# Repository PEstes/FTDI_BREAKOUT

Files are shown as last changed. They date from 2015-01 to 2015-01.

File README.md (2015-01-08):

# FTDI_BREAKOUT

A full featured FTDI FT232R breakout board which features almost all UART pins(RX,TX,DTR,RTS,CTS) broken out and also IO voltage selection feature
to either 3.3v or 5v IO.

<br /><span xmlns:dct="http://purl.org/dc/terms/" property="dct:title">FTDI BREAKOUT</span> by <span xmlns:cc="http://creativecommons.org/ns#" property="cc:attributionName">NeutroN StrikeR</span> is licensed under a <a rel="license" href="http://creativecommons.org/licenses/by-sa/4.0/">Creative Commons Attribution-ShareAlike 4.0 International License</a>.

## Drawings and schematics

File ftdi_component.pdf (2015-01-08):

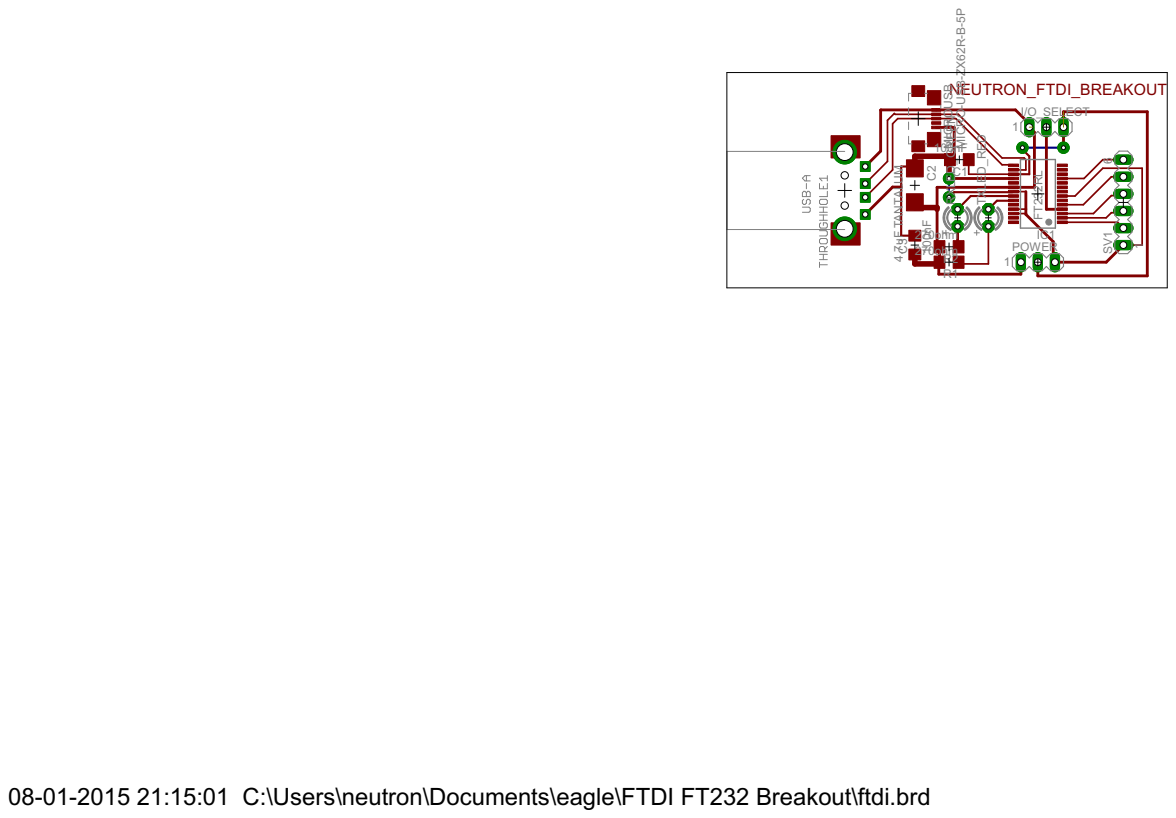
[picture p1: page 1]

08-01-2015 21:15:01 C:\Users\neutron\Documents\eagle\FTDI FT232 Breakout\ftdi.brd

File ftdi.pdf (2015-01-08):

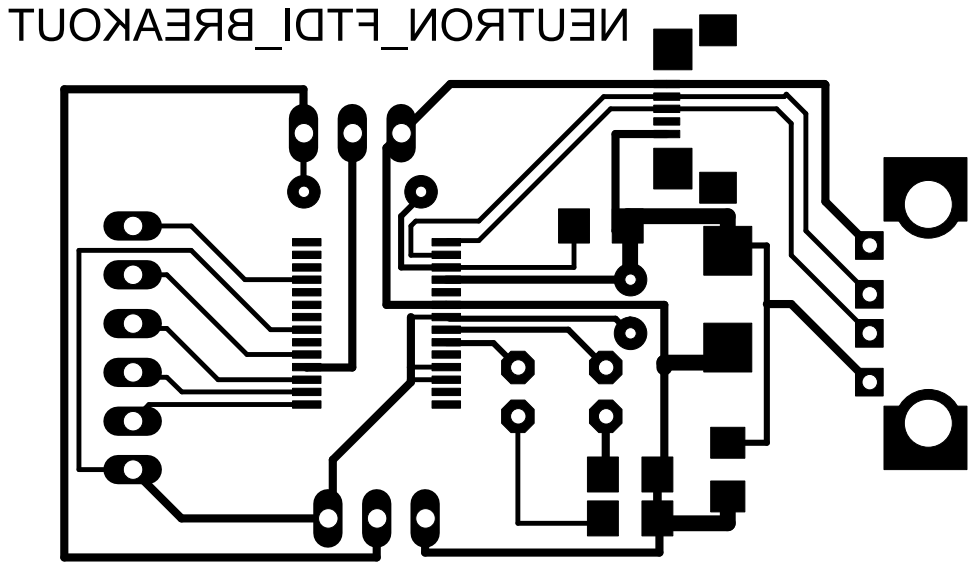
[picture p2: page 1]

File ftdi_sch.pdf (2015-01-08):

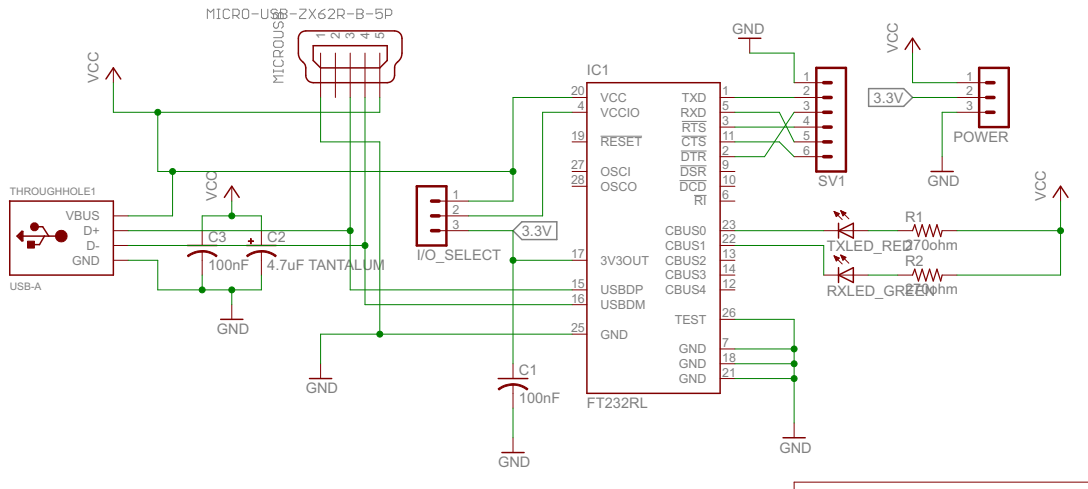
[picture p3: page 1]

08-01-2015 20:48:16 C:\Users\neutron\Documents\eagle\FTDI FT232 Breakout\ftdi.sch (Sheet: 1/1)

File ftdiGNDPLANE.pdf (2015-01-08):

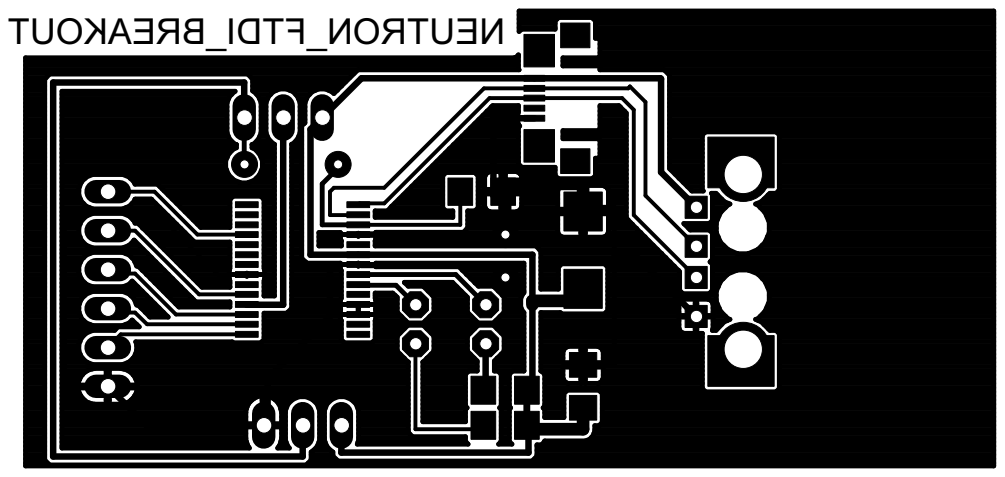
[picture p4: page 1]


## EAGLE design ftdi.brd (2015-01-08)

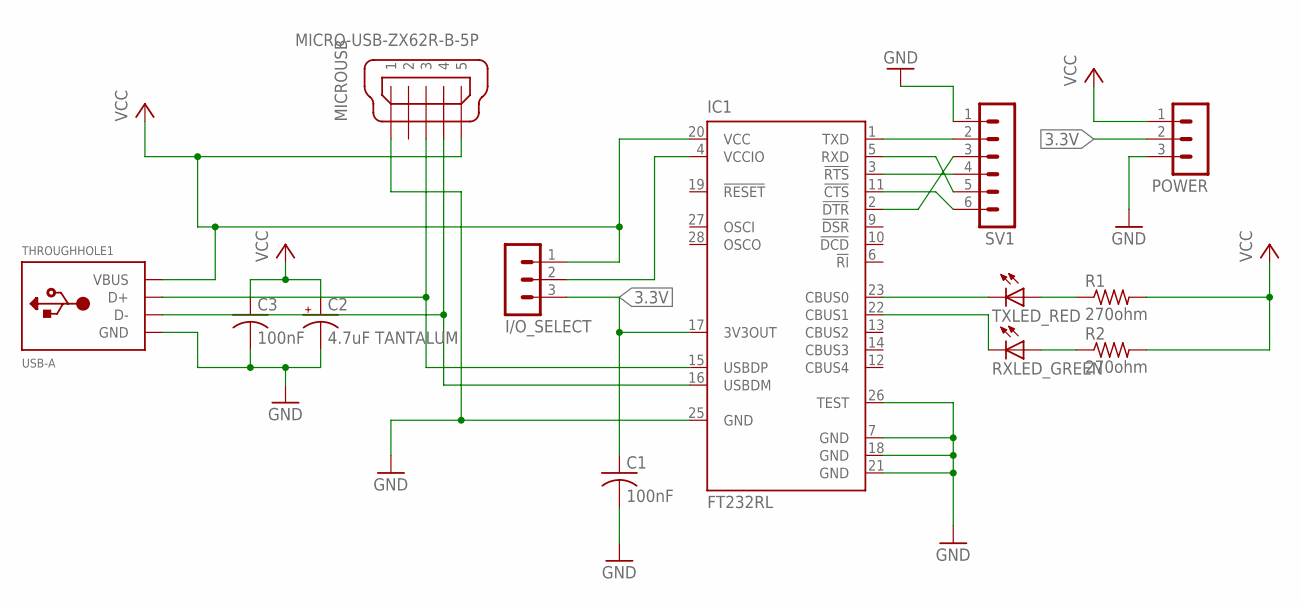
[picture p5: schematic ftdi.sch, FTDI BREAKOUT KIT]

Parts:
C1, C3: 100nF; C1206
C2: 4.7uF TANTALUM; C/6032-28R
I/O_SELECT: MA03-1
IC1: FT232RL; SSOP28
MICROUSB: MICRO-USB-ZX62R-B-5P; ZX62R-B-5P
POWER: MA03-1
R1, R2: 270ohm; R1206
RXLED_GREEN: LED3MM
SV1: MA06-1
THROUGHHOLE1: USB-A; MOLEX_480371000
TXLED_RED: LED3MM

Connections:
3.3V: C1.1, I/O_SELECT.3, IC1.17 (3V3OUT), POWER.2
GND: C1.2, C2.-, C3.2, IC1.7 (GND), IC1.18 (GND), IC1.21 (GND), IC1.25 (GND), IC1.26 (TEST), MICROUSB.1, POWER.3, SV1.1, THROUGHHOLE1.P$4 (GND)
unnamed: IC1.1 (TXD), SV1.2
unnamed: IC1.16 (USBDM), MICROUSB.4, THROUGHHOLE1.P$2 (D-)
unnamed: IC1.15 (USBDP), MICROUSB.3, THROUGHHOLE1.P$3 (D+)
unnamed: IC1.23 (CBUS0), TXLED_RED.K (C)
unnamed: I/O_SELECT.2, IC1.4 (VCCIO)
unnamed: R1.1, TXLED_RED.A
unnamed: R2.1, RXLED_GREEN.A
unnamed: IC1.2 (!DTR), SV1.3
unnamed: IC1.3 (!RTS), SV1.4
unnamed: IC1.5 (RXD), SV1.5
unnamed: IC1.11 (!CTS), SV1.6
RXLED_RED: IC1.22 (CBUS1), RXLED_GREEN.K (C)
VCC: C2.+, C3.1, I/O_SELECT.1, IC1.20 (VCC), MICROUSB.5, POWER.1, R1.2, R2.2, THROUGHHOLE1.P$1 (VBUS)

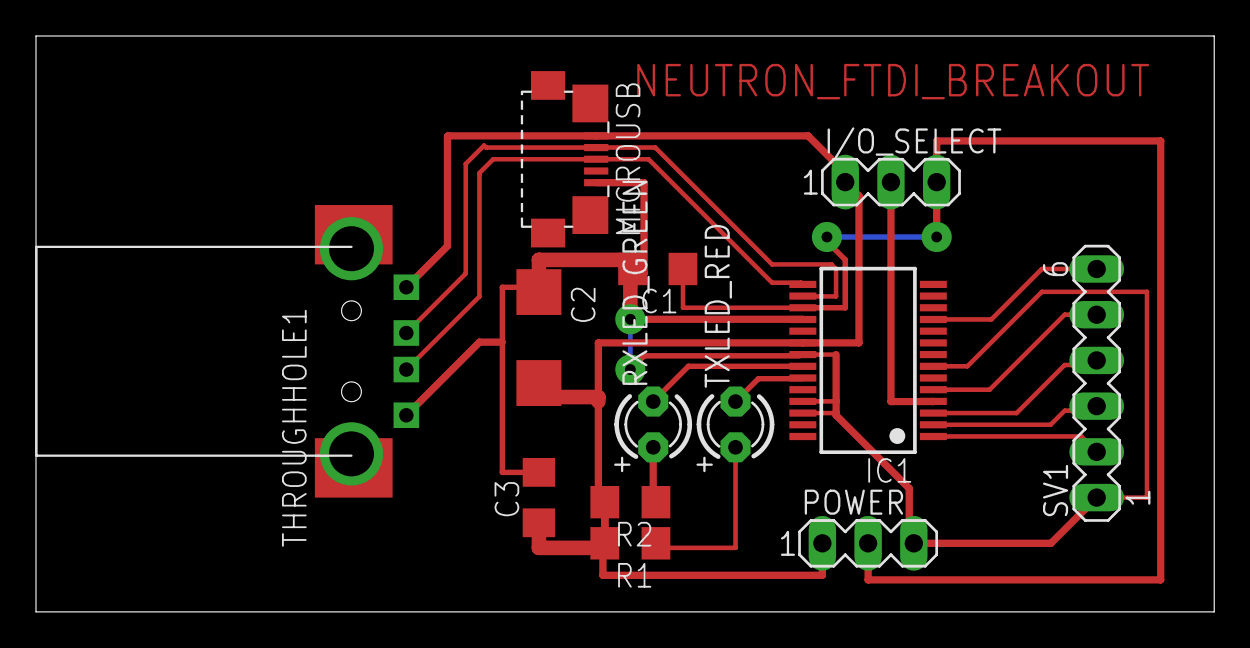
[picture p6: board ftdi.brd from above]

Board: 2 copper layers, 65.5 x 32.0 mm, 13 parts (0 on the bottom side), 15 nets.
